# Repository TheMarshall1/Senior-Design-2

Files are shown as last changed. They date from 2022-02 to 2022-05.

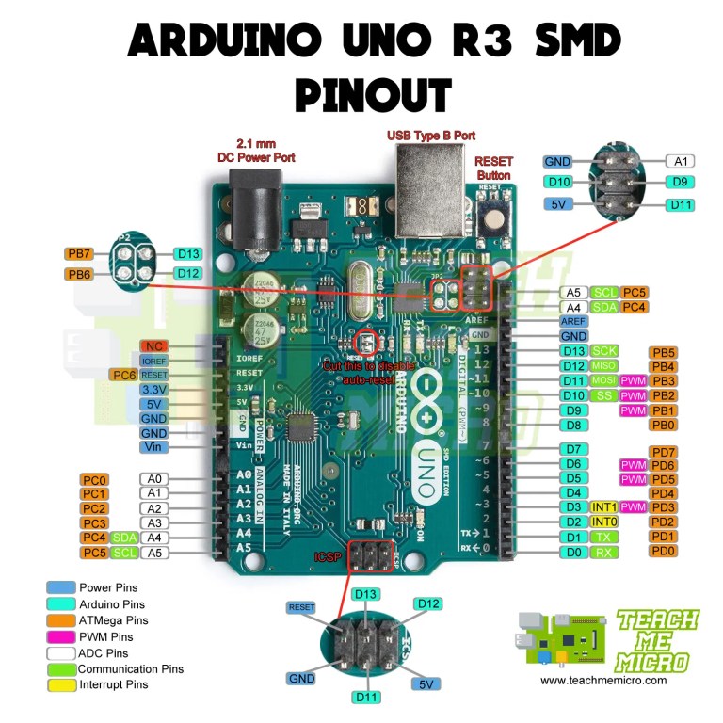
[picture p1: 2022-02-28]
DataSheet/PCB-Data/arduino pin layout.jpg

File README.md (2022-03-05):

# Team GoGetters
### Purpose, Objective, Introduction:
The problem our team is trying to tackle is wandering in dementia patients. Alzheimer’s
disease or other dementia causes people to lose their ability to recognize familiar places and
faces. It’s common for grandparents living with dementia to wander or become lost or confused
about their location, and it can happen at any stage of the disease. Although common,
wandering can be dangerous and the stress of this risk weighs heavily on caregivers and family.
### Solution:
The project is designed to give the patient around the clock care. It is a sensor system
consisting of two boards. First, a weight sensor that is located under the patient mattress and
motion sensor near the bed work together to collect and analyze data with an Arduino
microcontroller. Second, an IR sensor that is able to tell if the patient is leaving the room. The
code reads the input from the sensors on each of the two Arduinos (Client Arduino and Server
Arduino) and notifies the server Arduino directly or over wifi from the client Arduino. Then the
server Arduino changes the webpage to notify the user.
Scope:
Continuing from our first semester prototype, our team will focus on achieving the goals
defined in the Tasks and Deliverables section. This document will keep track of the task needed
to be done .
### Teams Link
https://teams.microsoft.com/l/channel/19%3aRfTW1WtWi_rlrrXjveJYQXDsdVA2zwDeV-sNyXwoO8I1%40thread.tacv2/General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

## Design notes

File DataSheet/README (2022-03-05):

This folder contains all the components' schematics and datasheet

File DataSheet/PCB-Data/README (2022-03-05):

This folder contain the general info for the battery/logic board designed by Khanh Le via Altium

Main functionality:

Battery Reverse Voltage Protection.
Low Battery Detection LED.
Alarm Signal Processing

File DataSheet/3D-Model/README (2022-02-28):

This Folder contains the 3D printed container's files and pictuces 
The components are sampled to create the container
The container is designed by Khanh Le using FreeCAD

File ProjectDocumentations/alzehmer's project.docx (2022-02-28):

8) Data configurationally management plan

Alzheimer's disease affects one out of every nine adults 65 and older as well as up. “On such an annual basis, family members expend upwards of $1 million dollars providing with someone with Alzheimer's disease. Sometimes households will have to forego vacations as a result of this. Individuals, but at the other hand, might even go desperate for food.”

These information, directly taken out from Alzheimer's Association, should provide anyone an idea of something like the difficulties that an individual experiences because they or a significant one seems to have Alzheimer's disease. As little more than a manufacturer, I considered this now and wanted to create a reusable gadget, a technology that really can assist both patients and family members.

That system will be able of doing at least those two activities:

- Encouraging the customer to complete regular chores (such as medications, exercise, etc)
- Monitoring your participant's location in the household; notify the caregivers inside the case of emergencies; and indicate the moment (it's a timepiece, and besides!)
- It really should be transportable as well as simple to be using, for even an elderly woman. It really should be inexpensive.

9) Software development model

It may have been used to identify if indeed the patients has collapsed as well as to determine where another patients would be in the house using precision temperature monitoring.

- Nokia 55-inch
- Touchscreen,
- Sensors
- Arduino
- HC-05 Transmitter And receiver

Methodology

This DPS310 atmospheric sensing element on Infineon's Encourage Interaction Nano development board provides data across wirelessly to the development board. Infineon's Mobile application, but also the SES2G assessment programme, can display pressure, temperature, and temperature measurements. Users can even use the Arduino library to create their customized Mobile application based on their needs. However, I'd like Alzheimer's Assistant to function with the use of a Samsung head in the middle. That should be a self-contained comfortable to wear with the ability to combine to a computer in order to examine data from the sensors. So, because of its small footprint size plus Wireless internet functionality, I chose to utilise another Arduino MKR1000 controller and interface it to the Encourage Interaction Micro or use some technique.

The Microcontroller MKR1000's configuration is as follows. Because I had an HC-05 bluetooth module on hand, I had to utilise it to link the Arduino MKR1000 to the Sensor Hub Nano. However, we must first wire the HC-05 towards the Arduino's hardware Tx & Rx pins, keeping into mind the transistor logic.

Because my wireless system operates as higher voltage, the same with the Construct different, no multilevel inverter translator was required. However, if my embedded system operates at 5 volts, you may need to utilise a pedestrian level. After we've matched the voltage levels, we'll really do have to couple the Administered intravenously now with Directly Interact Micro to begin transmission of data, and we'll need to figure out a simple way to have them pair periodically whenever the Directly Interact Micro comes within range of the network of something like the Makes the work.

To accomplish this, I decided to set up my HC-05 as a bluetooth'master' controller, pairing it mostly with one Network interface: the Directly Interact Nano's. So, even after you've configured it that way, when we power upon that HC-05, it looks for something like a gadget with such a specified Network interface (the Directly Interact Nano's) and immediately couples with this now, permitting the user to communicate with other devices.

Consequently HC-05's AT configuration parameters are used to accomplish this.

Code

// Original sketch from Martyn Currey's blog here:

// http://www.martyncurrey.com/arduino-with-hc-05-bluetooth-module-at-mode/

//

// Sketch modified by me to work with Arduino MKR1000!

//

// Basic Bluetooth sketch

// Connect the HC-05 module and communicate using the serial monitor

//

// The HC-05 defaults to commincation mode when first powered on.

// Needs to be placed in to AT mode

// After a factory reset the default baud rate for communication mode is 38400

char c = ' ';

void setup() {

// start the serial communication with the host computer

Serial.begin(9600);

Serial.println("Arduino with HC-05 is ready");

// start communication with the HC-05 using 38400

Serial1.begin(38400);

Serial.println("Serial1 started at 38400");

}

void loop() {

// Keep reading from HC-05 and send to Arduino Serial Monitor

if (Serial1.available())

{

c = Serial1.read();

Serial.write(c);

}

// Keep reading from Arduino Serial Monitor and send to HC-05

if (Serial.available())

{

c = Serial.read();

// mirror the commands back to the serial monitor

// makes it easy to follow the commands

Serial.write(c);

Serial1.write(c);

}

}

Final preparations

I could have used a Battery system with the Construct different but it does have a port for it. But then as We do not really have this at this present, I won't go into detail about it; nevertheless, if you ever need more details, your could visit the webpage for something like the Arduino Construct different.

We had 2 alternatives regarding recharging: visitors can use the MKR1000 USB connector directly, or you can use wireless charging if you have it. I'm going to use removable batteries for it. Because I already own an inductive charging transponders, that was not an option.

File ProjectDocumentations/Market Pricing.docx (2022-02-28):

Market pricing

The market pricing of the whole device will be roughly $170. It based on the area of the house we want to cover. In this price, the device will cover 3 bedrooms, a lounge, kitchen and 2 bathrooms. So, if the requirement of the space is more then, the price of the device will rise to $230-250 considering the need of more motion sensors and alarms.

Cost to make:

The motion sensors will cost about $50. More than 20 motion sensors will be required. When it comes to the Arduino microcontroller, the cost varies and if they will be bought in more quantity then their price will be less as compared to buying them individually. The price of a single unit is $15-20. Alarms and LEDs on the other hand will cost roughly $100 to buy and then integrating with the system.

Competitor

When it comes to the competition of this device, there are some devices of similar nature available in the market such as Tru Sense and Rest Assured, but these are not standalone devices. These are complete systems that need to be integrated within your house and they are based on monthly subscriptions. The cost models are not as effective as the proposed product “Grandma House”. This device is based on BOUF model (Buy Once Utilize Forever). Investment in this device is a one-time thing and it will last you almost forever considering the lifetime of Arduino microcontroller and the motion sensors.

Market Size

The market size of this product is not as vast as the baby monitoring devices because about 50 million people around the world have Alzheimer's disease or another type of dementia. The data set from the World Health Organization (WHO) revealed that about 60% of people living with dementia and/or Alzheimer’s are from a low or middle-income country throughout the globe. That is why the market size of devices of Grandma House nature are not as popular as the remote baby monitoring devices.

Sell Price/ Value

When it comes to the selling price or market value of this device. It can be considered as mediocre to high. Since there are no similar devices available in the market, it is safe to say that Grandma House: Alzheimer’s Monitoring Device is one of a kind that needs to be valued at a normal rate in the beginning so that people from all socioeconomic backgrounds can get to afford it. The data from WHO revealed that the global 60% population with Alzheimer’s disease is from middle-income earning countries. With the passage of time, the market value and the selling price will be increased as per the normal business models.

Percent Profit

For now, there is very less percent of profit from selling this device because we want the market and the target audience to be familiarized with it. Once the device is completely introduced to the intended audience, the profits can be estimated at 5% per device that means the profit will be $10 per unit.

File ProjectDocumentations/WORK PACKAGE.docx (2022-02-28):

WORK PACKAGE

- For this semester, there are quite a few things that still need to be done. The major items on my list, I will outline below.

Strain Ga. (Phuong) | IR (Abdul) | Build (Khanh) | Test (Mutlaq) | WiFi (Marshall) | Integration
Calibrate | Prox. Sensor | 3D model | Give parameters of the project | Setup | Make the story work
Weight-Value (The breakdown weight it can handle) | Daylight/Night | Hooking everything up | Environmental Factors (different lighting, door frames, bed weights) | Protocol | Keypad/finger sensor
Test | LED/Fluorescent | Battery(Arduino, Sensors) | | peer to peer | TA at Nov/20
Zeroize | code into arduino | Enclosure | | dhcp
Code into Arduino
arduino uno with HTTPS | arduino uno with HTTP

My task will be focus on how to test the project by give parameters of the project and environmental factors (different lighting, door frames, bed weights).

We worked this week with our project and we build it and connected the wight sensors and Arduino after we upload the code on it. Then we calibrated but it didn’t work. We plane to fix the code again and do the test again.

For next semester, there some of things need to be done. The major items on my list, I will outline below.

- Evaluate the project and correct any mistake from the previous semester.
- Rework on the design of the project and check availability of any sensors.
- Work on the finger touch and make alarm via SMS that the patient moved from the bed.
- Adjust the sensors on bed frame or on the door frame.

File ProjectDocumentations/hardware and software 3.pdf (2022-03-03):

Architecture Requirements
Task, Deliverable, or Feature Requirement | Description of Requirement
Powering the system | To power the system, we need to get 5volts, the supply will come from the mains ac source, then using a switching mode power supply we will convert the power from AC to 5v DC, the current should be minimum 2A to make sure that the system will operate in a good voltage level without flickering or dimming since we are using GSM modem and it requires 1A.
Connecting the Arduino to weighing sensor (using data pin and clock pin) | The load cell outputs cannot be connected directly to the Arduino, although Arduino board can detect small changes in voltage (4.9 mV) but this resolution still not enough for reading from the load cells, a dedicated amplifier board is being used to amplify the load cell voltage. To connect the sensor a synchronous serial protocol is used via two pins one for the data and the other for the clock signal.
Connect the load cells to the Hx711 board | The board Hx711 can be used with two or four cells, in this system we will use four load cells to put them under the bed legs, the four load cells will read the weight of the bed added to the human weight, hence controller can detect when the human leaves his bed.
GSM modem (Serial) | GSM modem communicates with the Arduino using two serial pins (Tx) which is the transmitter and this pin should be connected to a digital pin on the Arduino to work as receiver, the other pin is the (Rx) pin which is the receiver pin, this pin should be connected to digital pin on the Arduino board to act as serial transmitter

Software Requirements

IR sensors (Analog) | A set of two IR sensors will be used in this system, the output of the IR sensor is an analog voltage that is reverse proportional to the distance, a threshold will be assigned and the sequence of the sensors triggering will specify the movement direction, this method will be used to detect whether the patient is entering or leaving the room.
Task, Deliverable, or Feature Requirement | Description of Requirement
Arduino IDE | The Arduino integrated development environment is the platform needed for writing the Arduino code, the Ide can be installed on windows or mac laptops, even there is a web-based version of this software. All manufacturers of the sensor and actuators build a library for their product to make easier to use for Arduino developers, for this purpose the Arduino IDE can be loaded with tons of sensor libraries.
HX711 library | This board library helps to read the analog to digital conversion result, this board has 24bit ADC while the Arduino has 10bit ADC, this means high precision reading for small voltages coming from the load cells. The library has read command which will do the required communication with the board and get the result of the weight stored on the Arduino ram.
GSM library | GMS modem and most modem types are communicating with controllers using Serial protocols which is called UART (universal synchronous a synchronous receiver transmitter. This protocol will be used to send ASCII commands called (AT: attention) commands. For each GMS modem there are a pdf file that exactly specify the required AT command for doing certain task like sending SMS or make a call or even read the operator’s name and time.

IR sensor analog read | Ir sensor gives analog output , there are a library on the Arduino to read the analog voltage from any analog pins from A0 to A5.

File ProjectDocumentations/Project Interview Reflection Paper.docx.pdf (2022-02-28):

# Product Interview Reflection paper

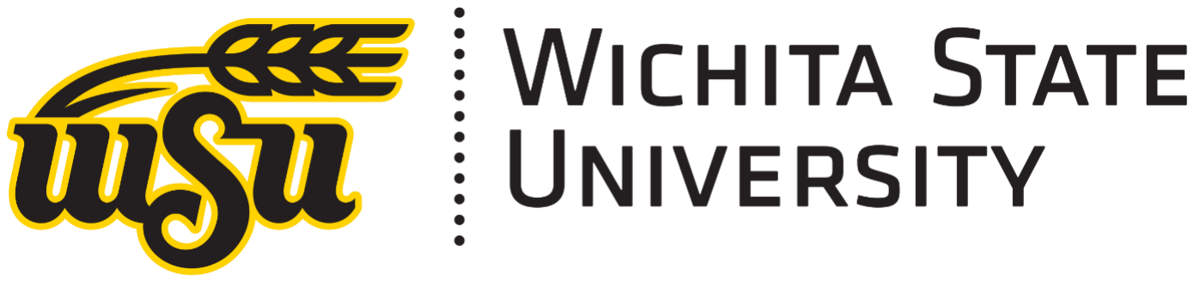
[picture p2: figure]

Class: EE 585

Team Name: Go Getter

Team Members: Marshall Aurell, Phuong Nguyen, Mutlaq Alotaibi, Khanh Le, Abdull Alhoulan

Project Name: Grandma’s House

Date: 11/7/2021

Introduction

With wandering being a major issue when it comes to helping people who

are dealing with dementia, there was a need for a solution. The Grandma’s House

system is a smart solution for the problem stated. Our system provides the

caretakers with a solution that will be able to identify when the risk of a person

with dementia is wandering around unattended and could seriously injure

themselves. During the week of November 7th we had the opportunity to ask

several people with diverse backgrounds a series of questions aimed at helping

our system cover a multitude of problems it could face. The information was

gathered and was analyzed by all team members. The team interviewed two

nurses at dementia & Alzheimer’s care centers, and a faculty member Md Rakib

Ur Rahman. The interviews covered these points, was there a product in place for

something like wandering, pricing, typical things we should know about the

patients to improve our project, and placement of the product to remain

concealed.

Body

Interview (1): Sandy from ComfortCare:

ComfortCare is an assisted living facility for dementia patients in Wichita,

KS. We informed her that our project is aiming to help caregivers of dementia

patients. We asked her how often the patients wander around and how far could

they wander? She said they are allowed to wander around the inside of the

building, but they must be accompanied by a caretaker outside the building. Then

we asked what kinds of sensors and systems that facility is using and how do they respond? Sandy said they have a bedtime alarm system in place that will sound an

alarm when it's time for them to go to bed.

Aslo, we asked how much did they spend on each sensor product and did

they have all the rooms installed with the product? She didn't have a price right

now but she also mentioned that healthcare products are expensive. We asked

Sandy would she spend $200 for a sensor system like ours? She replied yes, that

would be an awesome price range. Besides the strain gauges, Sandy said, the

facility is currently not using any types of motion detection or motion sensors to

detect patients are leaving their rooms. They would like our system to be able to

send a text message to someone that is on duty there and not to someone that

hasn’t checked in for the day. Also, the caretakers would like it if they would be

able to turn off the system when it is not needed.

Interview (2): Md Rakib Ur Rahman:

Rakib is an PhD electrical engineer student and a TA for the course. We set

up a meeting with him to ask about some technical issues the project may have.

We asked him about various problems regarding the project’s functionality. We

had a question for him about our battery powered board. After we did my

calculation for the power consumption, we thought that as the battery is drained,

the internal regulator of the Arduino won’t be able to keep up. Rakib advised us

that we should do some testing and get data voltage drop and the internal load of

the assembly first before deciding on if we want an extra regulator.

When asked about the environmental factors (different lighting, door

frames, bed weights) that can affect the system. He gives a suggestion about an

extra motion sensor and how we can arrange it around the bed frame. This extra motion sensor can eliminate some of the factors that we are worried about. One

other problem we asked him is about the project’s communication method. When

the system gets interrupted, we think it will not reboot correctly. Although he

cannot answer the question right away, he will connect us with someone who is

knowledgeable about the subject.

We asked him if we can use finger touch and he responded that we will work

on that if we are done with the test of our project.

Interview (3): Michelle from Brookdale:

Brookdale Senior Living owns and operates senior living communities and

retirement communities across the United States. We were able to talk with

Michelle for the interview. Michelle is currently working as a nurse for a Brookdale

facility in Wichita. We informed her about our project which aims to help

caregivers of dementia patients. She said that the sensor system would cause a

restraint to the staff and that they cannot use such a sensor system because it

would go against their company policy. Instead, they use call lights, fall mats, and

frequent checks (10 – 20 minutes). When we asked if the facility had any system

in place to prevent wandering. She mentioned that their building has an exit alert

system which would go off when someone without a passcode wanders outside.

Conclusion

Using these interviews, we can break down the main points that can be

learned regarding target market, product features, functionalities and pricing:

At first, the main vision for the project’s market was for resident homes. It

was designed to help family members of dementia patients to look after them better. But after the interviews with the care facilities, we learned that the scope

of the project should be modified toward these care centers. We have decided

that extra features should be added based on the feedback from these care

centers. The first changes would be instead of the 24/7 sensor system, we will

need to add an on/off button (could be a switch, keypad or fingerprint scanner).

Second, the sensor system should be able to integrate with their existing

employee management system. This integration would require a lot of time and

coding so we have decided to include this to next semester's workload.

As for the current functionalities of the product. We have decided to add an

extra motion sensor near the bed of the patient. This sensor will share the same

Arduino board as the strain gauge. This extra component will help create a more

accurate alert.

The main focus of this product is reliability and the affordability of each

product that we can provide for the customers. From the interview we conclude

that the customers want the products installed in their facility if the cost is

affordable for not only the facility but also the patients they are caring for. We

know it would cost a lot less to install the system to help prevent wandering and

monitoring the situation before the accident happens than in the situation that

the patients wandering around get lost or get hurt.

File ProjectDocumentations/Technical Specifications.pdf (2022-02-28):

# Technical Product Specification Paper

Class: EE 585

Team Name: Go-Getter

Instructor: Caskel Stallard

Date: 10/24/21

Product description: This device will consist of two parts. First, a sensor system that is located under the patient bed and throughout the house to collect and analyze data with an Arduino microcontroller. Each sensor will have an RF24 module and Arduino Nano to transfer data wirelessly. Second, an alarm that is designed to go off and send an SMS notification to the caregiver when the system indicates that grandma is doing something unusual.

General requirements:

- Indoor environment:
- Temperature Range: 60-80 F
- Humidity: 30-50%
- Internet service: wireless connection for LAN configuration.
- Telecommunication devices with service connection

Alternate Considerations:

Changes | Reason | Pros | Cons
Use IR sensor instead of PIR sensor | PIR has a wide detection range and will interfere with other PIR sensors when put in close proximity | _IR allow directional detection
Use SMS as an alarm instead of emails | People tend to check their messages more than emails | _SMS is more effective as a notification tool | _After using more than 90MB, we have to pay to use the service _Estimate around $5-10 per month
Use RF24 transceiver module | As the project scopes grow from a room to a house, wiring all the modules together is not practical. | _Allow wireless data transfer in | _Extra cost _Each module need its own power supply

Regulations:

- Battery:
- Follow the American National Standard for Portable Lithium Primary Cells and Batteries Safety Standard (ANSI C18.1M Part 1-2001).
- Wireless:
- The wifi has to comply with IEEE 802.11 n/g/b standard.

- The RF transceiver module must comply with FCC Equipment Authorization for RF Device (Products operating at 9 kHz to 3000 GHz have the potential to cause interference with radio services).
- Sensor: (Strain gauge, IR motion sensor)
- All boards must comply with RoHS Directive (lead-free solder finish and meet the
| restricted concentration levels for dangerous chemicals such as mercury,
| cadmium, hexavalent chromium, etc.)

Market pricing:
The market pricing of the whole device will be roughly $170. It is based on the area of the house we want to cover. At this price, the device will cover 3 bedrooms, a lounge, a kitchen, and 2 bathrooms. So, if the requirement of the space is more then, the price of the device will rise to $230-250 considering the need for more motion sensors and alarms.
Cost to make:
The motion sensors will cost about $5. More than 20 motion sensors will be required. When it comes to the Arduino microcontroller, the cost varies and if they will be bought in more quantity then their price will be less as compared to buying them individually. The price of a single unit is $15-20. Alarms and LEDs on the other hand will cost roughly $100 to buy and then integrate with the system.
Competitor:
When it comes to the competition of this device, there are some devices of similar nature available in the market such as True Sense and Rest Assured, but these are not standalone devices. These are complete systems that need to be integrated within your house and they are based on monthly subscriptions. The cost models are not as effective as the proposed product “Grandma House”. This device is based on the BOUF model (Buy Once Utilize Forever). Investment in this device is a one-time thing and it will last you almost forever considering the lifetime of the Arduino microcontroller and the motion sensors.
Market Size:
The market size of this product is not as vast as the baby monitoring devices because about 50 million people around the world have Alzheimer's disease or another type of dementia. The data set from the World Health Organization (WHO) revealed that about 60% of people living with dementia and/or Alzheimer’s are from a low or middle-income country throughout the globe. That is why the market size of devices of Grandma House nature is not as popular as the remote baby monitoring devices.
Sell Price/ Value:
When it comes to the selling price or market value of this device. It can be considered mediocre to high. Since there are no similar devices available in the market, it is safe to say that Grandma House: Alzheimer’s Monitoring Device is one of a kind that needs to be valued at a normal rate in the beginning so that people from all socioeconomic backgrounds can afford it. The data from WHO revealed that the global 60% population with Alzheimer’s disease is from middle-income earning countries. With the passage of time, the market value and the selling price will be increased as per the normal business models.
Percent Profit

For now, there is very little profit from selling this device because we want the market and the target audience to be familiarized with it. Once the device is completely introduced to the intended audience, the profits can be estimated at 5% per device that means the profit will be $10 per unit.
Software details :
1. Each Arduino will be equipped with an RF24 that will send a signal back to the main Arduino wirelessly, then the main Arduino will interpret the information and will send an SMS message to the caretaker's phone.
2. A recording device will have the following sensors attached:
a. IR Sensor / Weight Sensor
b. Fingerprint Scanner (Deactivate the system if a caretaker is going into that location. And reactivate the system when caretaker leaves)
3. Depending on the location of the sensors it will notify the caretaker of the whereabouts of the patient by sending an SMS message to their mobile devices

Design Specifications (Hardware):

- The product will come with 3 different modules minimum, all batteries powered. All
| modules will have an enclosed, rectangular case.
- The RF24 transceiver network (communication method between Arduino units/modules) must be able to operate with 20+ nodes within a 1500-2500 sq ft residence.
- Case enclosure must meet IP64 of International Protection ratings, meaning it offers total
| protection against dust and protection against water splashes from all directions.

Design Specifications

Arduino Processor Board

| Dimensions | 13.7 x 8.4 x 1.85 in.

| Weight | 2.15 lbs.
| Operating Voltage | 3.3 V to 12 V
| Compatible | PC and Mac
| Software | Arduino IDE

Battery Cell

| Voltage | 12 V

LED

| Color | Red, Yellow, Blue, Green

RF24 Receiver Module

| Operating Voltage | 3.3 V
| Range | 50 to 200 feet
| Frequency Range | 9 kHz to 2.4 GHz

Weight sensors

| Load Weight (4 pieces) | 50 Kg. X 4

HX711 AD Module

| Operating Voltage | 2.6 V – 5.5 V

| Item Weight | 2.8 ounces
| Dimension | 5.71 x 4.17 x 0.67 in.

Infrared Proximity Sensor

| Dimensions | 29.5 x 13 x 21.6 mm
| Range | 20 to 150 cm
| Operating Voltage | 4.5 V to 5.5 V

WIFI

| Comply With | IEEE 802.11 n/g/b standard

Communication

| Type | SMS

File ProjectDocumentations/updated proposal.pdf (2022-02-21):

## Team GoGetter

### Project Proposal

Product Title:

“Grandma House”

Primary Project Proposal:

Alzheimer’s disease or other dementia causes people to lose their ability to recognize familiar places and

faces. It’s common for grandparents living with dementia to wander or become lost or confused about

their location, and it can happen at any stage of the disease. Although common, wandering can be

dangerous and the stress of this risk weighs heavily on caregivers and family. The project is designed to

detect your grandma or loved one's rising from bed by monitoring his/her body weight and motion. It

also detects the location of grandma within the house. An alarm will go off when the system detects

anything “abnormal” about the grandma's location.

Product Description:

This device will consist of two parts. First, a sensor system that is located under the patient bed and

throughout the house to collect and analyze data with an Arduino microcontroller. Second, an alarm/LED

that is designed to go off when the system indicates that grandma is doing something “abnormal”.

Requirements:

1. Using weight sensors such as strain gauge to determine when the patient leaves their bed.
2. Using different motion sensors and infrared sensors to determine when the patient (leaves their

room/enters another room).

4. Transmission of all collected data to a microprocessor (Arduino) and send it to a web server.
5. When the patient leaves their bedroom during an unwanted time and the movement system indicates

that the patient has left the room/house, the system will set an alarm to notify their caregivers.

6. The system will be hidden out of sight and without any wearable accessories.
7. Integrate the alarm and the sensor system with wireless communication (RF transceiver)

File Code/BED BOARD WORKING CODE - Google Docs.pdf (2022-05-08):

//Include Libraries
#include <SPI.h>

#include <nRF24L01.h>

#include <RF24.h>

#include "HX711.h"

#define pir 4

const int LOADCELL_DOUT_PIN = 2; const int LOADCELL_SCK_PIN = 3; float a;
float b=60;

HX711 scale;
//create an RF24 object
RF24 radio(9, 8); // CE, CSN

//address through which two modules communicate. const byte address[6] = "00001";

void setup()
{
pinMode(pir,INPUT);
radio.begin();

//set the address
radio.openWritingPipe(address);

//Set module as transmitter
radio.stopListening();

Serial.begin(9600);
scale.begin(LOADCELL_DOUT_PIN, LOADCELL_SCK_PIN);

scale.set_scale(2280.f);
scale.tare();
}
void loop()
{
if (digitalRead(pir)==1){
Serial.println("Motion detected"); delay(1000);
}

Serial.print("one reading:\t"); Serial.print(scale.get_units(), 1); Serial.print("\t| average:\t"); Serial.println(scale.get_units(10), 1);
a = scale.get_units(10);

if (a>b && digitalRead(pir) == 1){ Serial.print("Some one is on bed and moving\n"); const char text[] = "ON bed moving"; //13 char radio.write(&text, sizeof(text));
delay(1000);
}
else if (a<b && digitalRead(pir) == 1){
Serial.print("Some one is NOT on bed and moving \n"); const char text[] = "NOT bed moving"; //14 char radio.write(&text, sizeof(text));
delay(1000);
}
else if (a>b && digitalRead(pir) !=1){ Serial.print("Some one is on bed and not moving \n"); const char text[] = "ON bed not moving"; //17 char radio.write(&text, sizeof(text));
delay(1000);
}
else if(a<b && digitalRead(pir) !=1){
Serial.print("Some one is NOT on bed and not moving \n"); const char text[] = "NOT bed not moving"; // 18 radio.write(&text, sizeof(text));
delay(1000);
}
scale.power_down(); | // put the ADC in sleep mode
delay(5000);
scale.power_up();

}

DOOR BOARD

//Include Libraries
#include <SPI.h>

#include <nRF24L01.h>

#include <RF24.h>

//create an RF24 object
RF24 radio(9, 8); // CE, CSN

//address through which two modules communicate. const byte address[6] = "00001";

#define sensor1 5 //black In IR

#define sensor2 6 //white Out IR #define alarm1 2

#define alarm2 3

#define sms 4

#define LED 7

char dir;

void setup()
{
while (!Serial);
Serial.begin(9600);
radio.begin();

//set the address
radio.openReadingPipe(0, address);

//Set module as receiver
radio.startListening();

pinMode(alarm1, OUTPUT);
pinMode(alarm2, OUTPUT);
pinMode(LED, OUTPUT);
pinMode(sms, OUTPUT);
pinMode(sensor1,INPUT_PULLUP); pinMode(sensor2,INPUT_PULLUP);

dir='x';

}

void loop(){

digitalWrite(alarm1,HIGH); digitalWrite(alarm2,HIGH); digitalWrite(sms, HIGH);
digitalWrite(LED, LOW);
const char a[32]={"ON bed moving"}; //14 const char b[32]={"NOT bed moving"}; //15 const char c[32]={"ON bed not moving"}; //18 const char d[32]={"NOT bed not moving"}; //19 char text[32]={0};
int w;
//Read the ata if available in buffer

if (radio.available())
{
radio.read(text, sizeof(text)); //String mytext =String(text); Serial.println(text);
//w= mytext.length();
}

if (digitalRead(sensor1)==0){//sensor 1 detects object

if (dir=='x'){//if the last movement was unkown dir='o';//movement is out going
//give 2 seconds before ignoring the direction
Serial.println("direction is Out");
delay(1000);

if (dir =='o'&& (sizeof(text)== sizeof(b) || sizeof(text)== sizeof(c)) ){ //still not bed not moving || not on bed while moving (18 || 14)
digitalWrite(alarm1, LOW);
digitalWrite(alarm2, LOW);
digitalWrite(sms, LOW);
delay(1000);

}
else if (dir =='o' && (sizeof(text)== sizeof(a) || sizeof(text)== sizeof(d))){ //still on bed not moving && still on bed while moving (17 || 13)
digitalWrite(LED, HIGH);
delay(1000);

}
dir='x';
}
}

if (digitalRead(sensor2)==0){//sensor 2 detects object

if (dir=='x' && sizeof(text)==sizeof(a)){//if the last movement was unkown dir='i';//movement is out going
//give 2 seconds before ignoring the direction
Serial.println("direction is IN");
dir='x';
delay(1000);
}

}

}

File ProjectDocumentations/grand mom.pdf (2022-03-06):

Ac power supply

In this report I will explain the power supply details for powering the circuit, the input

will be taken from the AC power outlet which is 110V AC,

The first step is to convert the ac voltage to DC voltage using SMPS, the adapter will

be selected to give 12V DC, although we need 5volt to supply the circuit but we will

use 12v adapter to use a buck converter that will step down the dc 12 volt to 5v dc, the

use of another stage for getting 5volts is due to the need for constant 5volts as will as

over current protection board.

Figure below shows the power adapter that will give 12v dc to the circuit

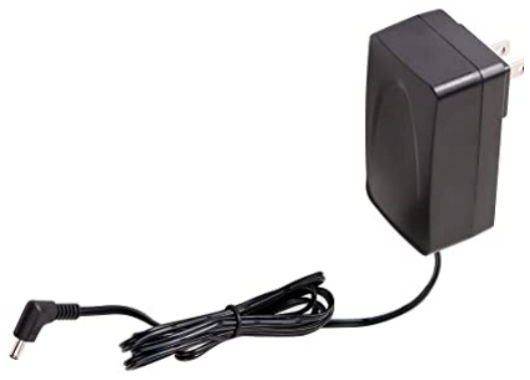
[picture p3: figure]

Features and specs of the adapter as taken from the reference 1

- AC input ranges from 100V to 240V, 50Hz/60Hz, 0.8A Max; DC output 12V 2A
- 12v 2a AC adapter with 4ft long cable enables you to conveniently make an

easy connection

Figure below shows the Buck converter which will step down the voltage from 12V DC to 5V DC and at the same time it does the overcurrent protection as well as the over

temperature protection

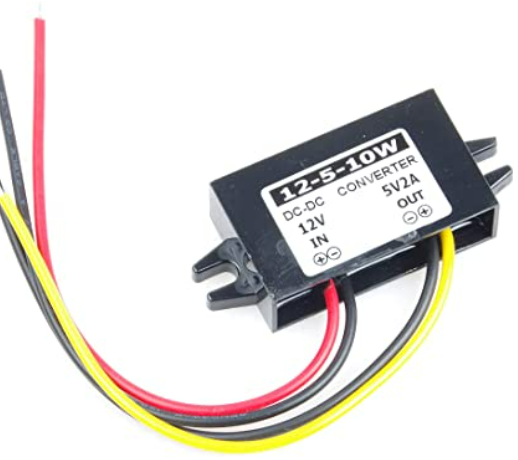
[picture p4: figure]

Features and specs as taken from reference 2

- Synchronous rectification, efficient, stable and reliable.
- Input voltage: 12V (higher than the output voltage of 3V) the maximum 20V

(DC 8- 22V)).

- With over-temperature protection
- overcurrent protection
- short circuit protection
- Output voltage: 5V
- Conversion efficiency: > 93%.
- Waterproof level: IP67.Shockproof

Finally figure below shows the connection diagram of the power supply circuit, it will

take the 110v from the power socket and convert it to 12v using the power adapter,

then the buck converter will stepdown the voltage to 5volts and make the required

protections, over heating and short circuit protection and also the over current, on the

output of the buck converter we added the switch button to turn on/off the supply

voltage

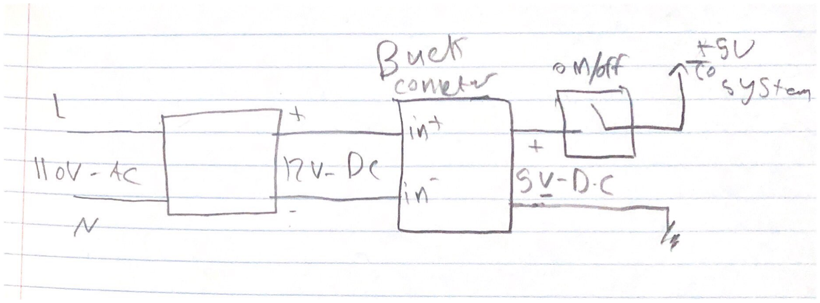
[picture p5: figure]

Reference

1. https://www.amazon.com/DTECH-Adapter-Supply-1-35mm-Charger/dp/

B082XWGGKJ/ref=sr_1_2_sspa?

crid=MFZ37N9MYEPA&keywords=smps+12v+2a&qid=1646465403&spr

efix=smps+12v+2%2Caps%2C225&sr=8-2-

spons&psc=1&spLa=ZW5jcnlwdGVkUXVhbGlmaWVyPUFGNUZLV1hBM

UNPSkcmZW5jcnlwdGVkSWQ9QTA2NzM2MjVCVDFJSk9GN0paM1kmZ

W5jcnlwdGVkQWRJZD1BMDUyMDQ3NlExT1FNQjVZOUc1VSZ3aWRnZX

ROYW1lPXNwX2F0ZiZhY3Rpb249Y2xpY2tSZWRpcmVjdCZkb05vdExvZ0

NsaWNrPXRydWU= (https://www.amazon.com/DTECH-Adapter-Supply-1-35mm-Charger/dp/B082XWGGKJ)

2. https://www.amazon.com/KNACRO-Synchronous-Over-Temperature-

Over-Current-Protection/dp/B08RMYX25Y/ref=sr_1_4?

crid=1WTHOJL2SN8S9&keywords=buck+converter+overcurrent+protect

ion&qid=1646465948&sprefix=buck+converter+overcurrent+protection%

2Caps%2C224&sr=8-4 (https://www.amazon.com/KNACRO-Synchronous-Over-Temperature-Over-Current-Protection/dp/B08RMYX25Y)

3.

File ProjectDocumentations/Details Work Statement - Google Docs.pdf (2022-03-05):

- Hardware requirements will be completed.
Deliverables | Assigned to | Due Date (Week/Date)
Possible Logic PCB to analyze the logic (Altium) ● Input: from all the function in the code ● Output: a signal connected port #(SMS function) to generate a SMS when high ● Design schematic, footprint, component library, PCB layout. | Khanh Le | 2/13 (Week 4)
Transceiver testing to transfer information between Arduino boards ● Ability to send an input to another arduino through the use of a transceiver channel ● Code the software to set up a communication pathway between both transceivers | Marshall | 2/27 (Week 6)
New 3D printed enclosure ● Update for new circuit+ power supply+wires from last semester | Khanh Le | 3/20 (Week 9)
Alarm Logic for the whole system ● Digital design*(help with memory storage) ○ Logic diagram ○ Logic map | Khanh Le | 2/20 (Week 5)
SMS module ● Research (due 2/20) ● Use SIM card to send SMS | Mutlaq | 2/27 (Week 6)
On/Off Switch for power supply ● A switch ● Circuit protection (diode) | Phong | 2/27 (Week 6
AC power supply compatible ● Circuit protection | Abdul | 2/27 (Week 6)

Software requirements will be completed.

Deliverables | Assigned to | Due Date (Week/Date)
Read and auto calibrate/zeroize strain gauge function (Github) ● Input: Take digital signal from strain gauge. ● Calibrate: translate the signal to a unit of measurement (kg) ● Zeroize: Zero out the weight detected in the first 15 second ● Output: A signal to the logic board | Phong | 2/27(Week 6)
Detect movement, IR break function (Github) ● Input: Take analog signal from sensors ● Output: A signal to the logic board ● Take into account light sources, distances,... | Abdul | 2/27 (Week 6)
Wifi Connection Function(Github) ● Option 1: Use two Arduino Uno to make a host and client network. Let the host control the web server and host a webpage. Allows clients to access webpage and keep track of the alarm status ● Option 2: Same thing, but using transceivers to tie the two arduinos together and using SMS to notify the caretakers | Marshall | 2/27 (Week 6)
Wifi Web Page UI (Github) ● User friendly/ working interface ● Shows alarm status ● Shows current data of sensors? | Marshall | 3/13 (Week 8)
Sending SMS Function (Github) ● Input: Take data from sensors ● Output: Alarm caretakers if sensor data is in the parameters | Mutlaq | 3/6 (Week 7)
Add time to Arduino and webpage (Github) ● Connect the Arduino to wifi and using the NTP to get the time and date ● Or RTC clock | Abdul | 3/6 (Week 7)

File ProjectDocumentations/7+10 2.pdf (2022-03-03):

### 7 ACQUISITION SCHEDULE

To achieve the project goals, we must divide our work into small tasks and we will

allocate a certain time period for each task, every task is a milestone in the project and

has to be done at the dedicated time in order to open the working process of the next

task, the main controller will monitor all the inputs and outputs is the Arduino board, it

will sense the human weight using four load cell that will be installed under the user

bed for example installing a load cell on each leg of the bed, the load cells will

measure the bed weight including the weight of user, and will detect the user existence

depending on the weight.

Week | Acquisition Schedule: 1 st Semester | Cost
Week 6 | • Studying the block diagram • Search for desired components • Compare prices and delivery dates | --
Week 7 | • Ordering main controller :15$ • Power supply 5v:12$ • Wires: 10$ • Usb cable 3$ | 40$
Week 8 | Purchase the weight sensor parts • 4 pcs 50kg Load Cells • HX711 | 12$
Week 9 | • Ordering IR sensors (detecting incoming or outgoing persons), this sensor should cover 1.5 meter with break beam sensing | 32$
Week 10 | Ordering WIFI modem • ESP8266 • Programming board (uploading code) | 20$
Week 11 | Ordering the prototyping components • Box • Base • connectors | 50$

### 10 FIRST SEMESTER SCHEDULE

The following table describes MLG’s first semester schedule:

Week 12 | Finalize the prototype | --
Week 13 | • Make desired modifications to both system and software | --
- TOTAL | | 154$
Week | Deliverable
Week 6 | • Design the system block diagram • Check compatibility between components
Week 7 | • Decide the main controller board • Decide the IDE for developing the code
Week 8 | • Ordering the components • Research about the available IOT clouds supported by the main controller board
Week 9 | • Assembling the weight sensor to the main controller • Develop test code to read and display weight
Week 10 | • Assembling IR sensors to the main board • Develop testing code for sensors
Week 11 | • Connect WIFI modem to main board • Program WIFI modem to connect to local Wi-Fi network • Develop code to send and receive data to WIFI modem
Week 12 | • Configure the selected IOT server to connect to our device • Program Wi-Fi modem with the desired IOT credentials • Send data from controller to cloud
Week 13 | • Run overall test • Make desired modifications to both system and software
Week 14 | • Finalize the final prototype • Make final real tests and modifications

Week 15

- Document the steps of work • Draw the final schematics and connections • Prepare and plan for next steps.

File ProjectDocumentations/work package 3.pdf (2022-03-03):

## Work package

In general, we are going to discuss how this system is going to be built, the tasks

needed to be performed as well as the required resources that must be existed to build

the system, for this purpose we need first to introduce the general idea of the system

that must be achieved then we will discuss the methods needed perform it

The main controller that will monitor all the inputs and outputs is the Arduino board, it

will sense the human weight using four load cell that will be installed under the user

bed for example installing a load cell on each leg of the bed, the load cells will

measure the bed weight including the weight of user, and will detect the user existence

depending on the weight.

To connect the load cells to the Arduino a special amplifier is required because the

output voltage of the load cells is very low.

Also, there are two IR obstacle sensors installed at the room entrance, we will use two

sensors to detect the person movement direction, if sensor1 triggered first then sensor

two this means the person is entering the room and if sensor two then sensor one, this means that the person is leaving the room.

Finally, the Arduino will send SMS to the responsible person telling him that the patient

left the room, this will be done by adding a GSM modem to the controller

Work needed to be performed

This system includes the following main field of knowledge

- Hardware assembling: this part should be easy and the connection diagram

between the components are available from the manufacturers

- Arduino programming: Arduino needed to be programmed using the Arduino

IDE program running on windows, programming requires good knowledge in C

programming.

- GSM modem: the GSM modem programming requires good knowledge and

skills in communication as well as the AT command for communicating with the modem, but fortunately there are a lot of Arduino libraries that deals with GSM

modems to send and receive messages.

Needed resources:

- Laptop for programming the Arduino
- Arduino IDE for writing the code
- SIM card to be inserted in the modem to send SMS
- Voltmeter to measure the system voltage and to test the IR sensor

Steps to finish the work

steps | Deliverable
Step1 | • Design the system block diagram • Check compatibility between components
Step2 | • Decide the main controller board • Decide the IDE for developing the code
Step3 | • Ordering the components • Research about the available GSM modems
Step4 | • Assembling the weight sensor to the main controller • Develop test code to read and display weight
Step5 | • Assembling IR sensors to the main board • Develop testing code for sensors
Step6 | • Connect GSM modem to main board
Step7 | • Configure the selected GSM to send SMS • Send data from controller to mobile phone
Step8 | • Run overall test • Make desired modifications to both system and software
Step9 | • Finalize the final prototype • Make final real tests and modifications
Step10 | • Document the steps of work • Draw the final schematics and connections • Prepare and plan for next steps.

Required products to finish the work

To achieve the project goals, we must divide our work into small tasks and we will

allocate a certain time period for each task, every task is a milestone in the project and

has to be done at the dedicated time in order to open the working process of the next

task, the main controller will monitor all the inputs and outputs is the Arduino board, it

will sense the human weight using four load cell that will be installed under the user

bed for example installing a load cell on each leg of the bed, the load cells will

measure the bed weight including the weight of user, and will detect the user existence

depending on the weight.

part | Acquisition Schedule: 1 st Semester | Required time (hours) | Cost
Arduino | • Ordering main controller :15$ • Power supply 5v:12$ • Wires: 10$ • Usb cable 3$ | 30 | 40$
Weight sensor | Purchase the weight sensor parts • 4 pcs 50kg Load Cells • HX711 | 10 | 12$
sensor | • Ordering IR sensors (detecting incoming or outgoing persons), this sensor should cover 1.5 meter with break beam sensing | 10 | 32$
GSM | Ordering GSM modem | 20 | 20$
casing | Ordering the prototyping components • Box • Base • connectors | 30 | 50$
- TOTAL | | | 154$

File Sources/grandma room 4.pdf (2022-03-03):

## Grandma room Block diagram

To achieve the project goals, we proposed the general block diagram shown in figure

1, the main controller that will monitor all the inputs and outputs is the Arduino board, it

will sense the human weight using four load cell that will be installed under the user

bed for example installing a load cell on each leg of the bed, the load cells will

measure the bed weight including the weight of user, and will detect the user existence

depending on the weight.

To connect the load cells to the Arduino a special amplifier is required because the

output voltage of the load cells is very low.

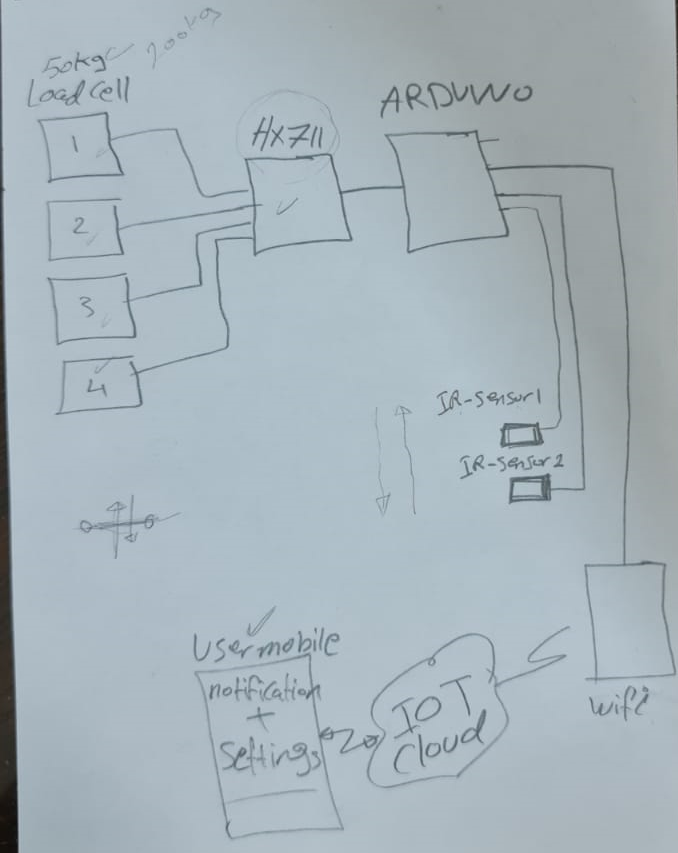
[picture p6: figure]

Figure 1 system block diagram

1

Also, there are two IR obstacle sensors installed at the room entrance, we will use two

sensors to detect the person movement direction, if sensor1 triggered first then sensor

two this means the person is entering the room and if sensor two then sensor one, this

means that the person is leaving the room.

Finally, the Arduino will upload the data and the notification to an IOT cloud using a Wi-

Fi connected to the Arduino, then the supervisor can open a dedicated mobile

application to connect his mobile to the cloud to monitor all sensors and get all

notifications, by using the IOT technology the mobile application can receive the data

from anywhere as long as the mobile has internet connection.

2

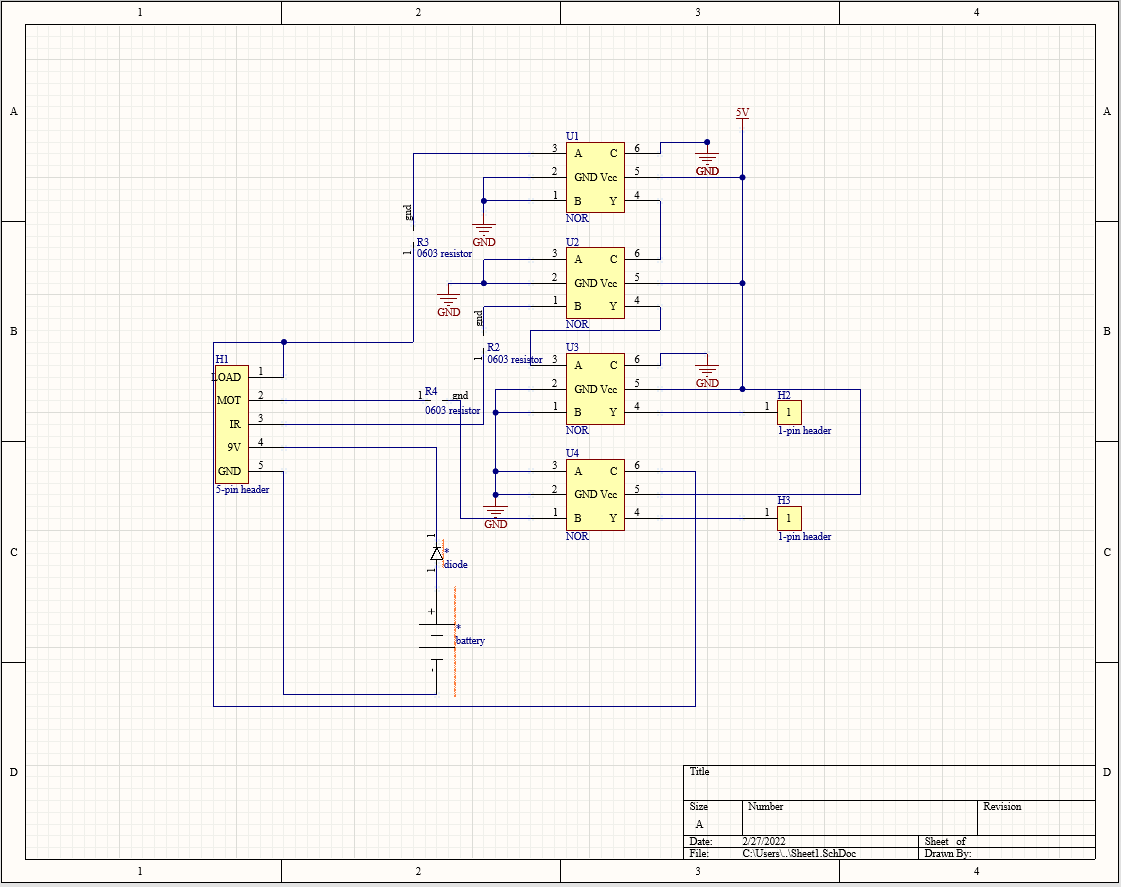
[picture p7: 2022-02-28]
DataSheet/PCB-Data/PCB-schematic.PNG

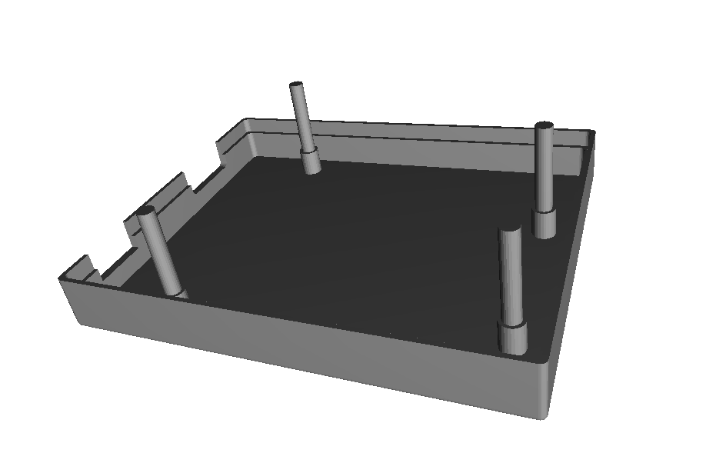
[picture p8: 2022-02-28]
DataSheet/3D-Model/bottom.png

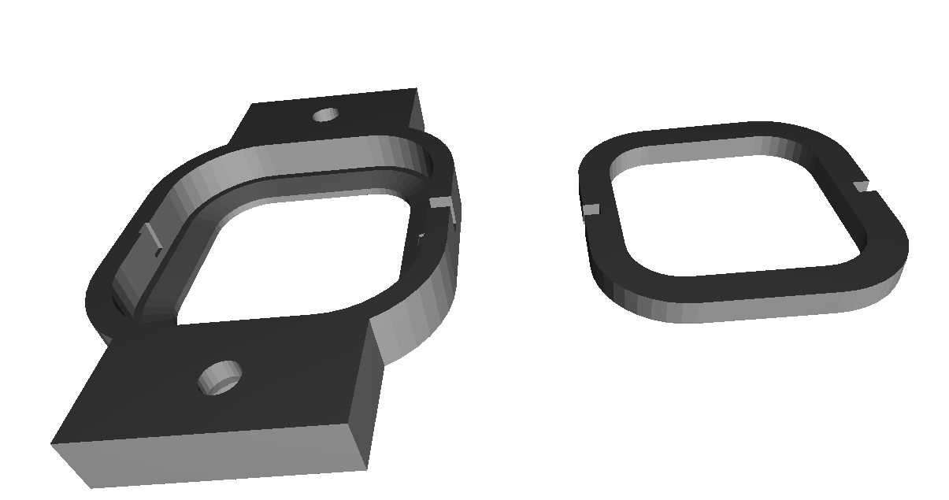
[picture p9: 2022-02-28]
DataSheet/3D-Model/loadcell.png

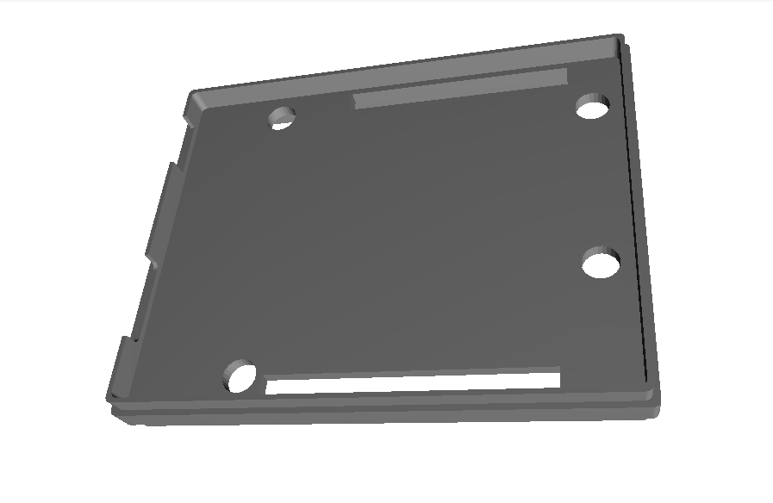
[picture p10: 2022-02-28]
DataSheet/3D-Model/middle.png

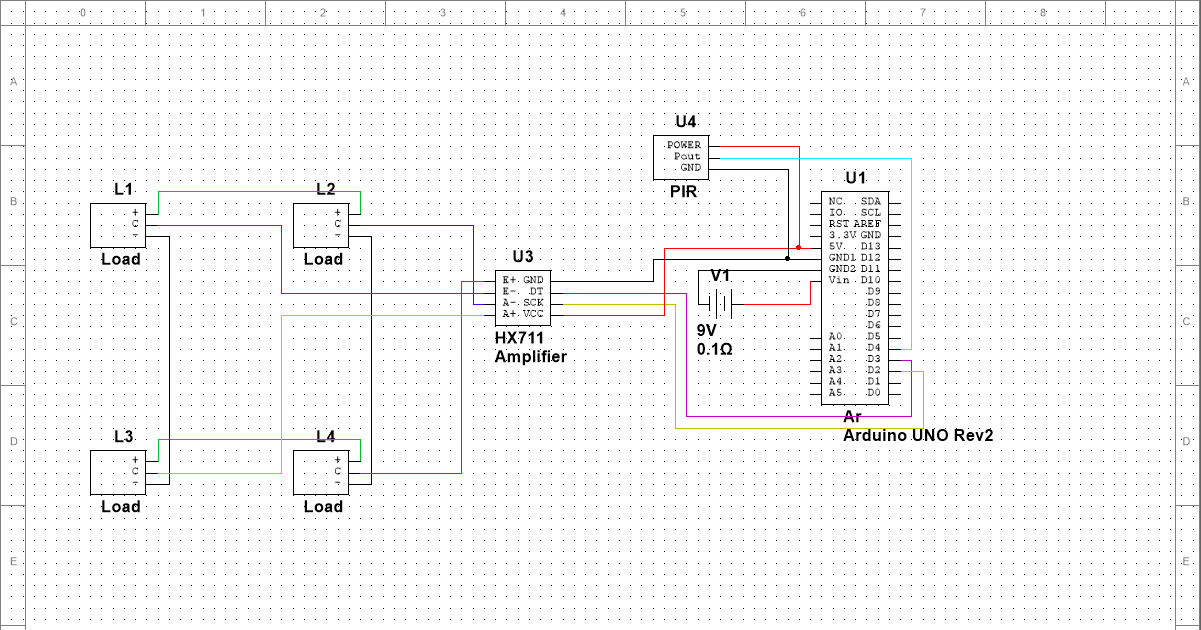
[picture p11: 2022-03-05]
DataSheet/Strain G.PNG

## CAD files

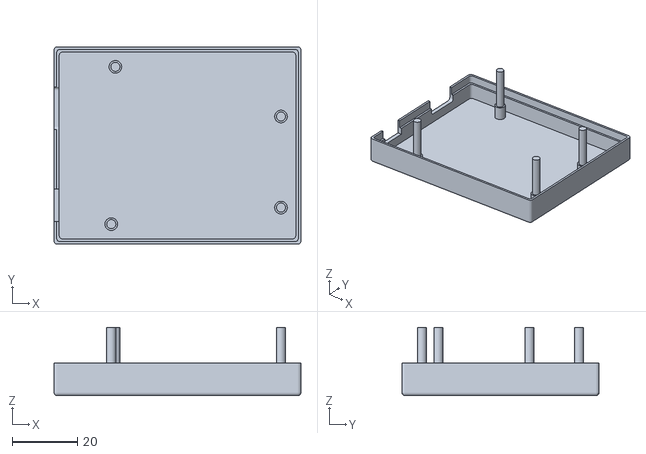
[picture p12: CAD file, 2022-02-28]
DataSheet/3D-Model/bottom.stl
75.8 x 60.5 x 21.0

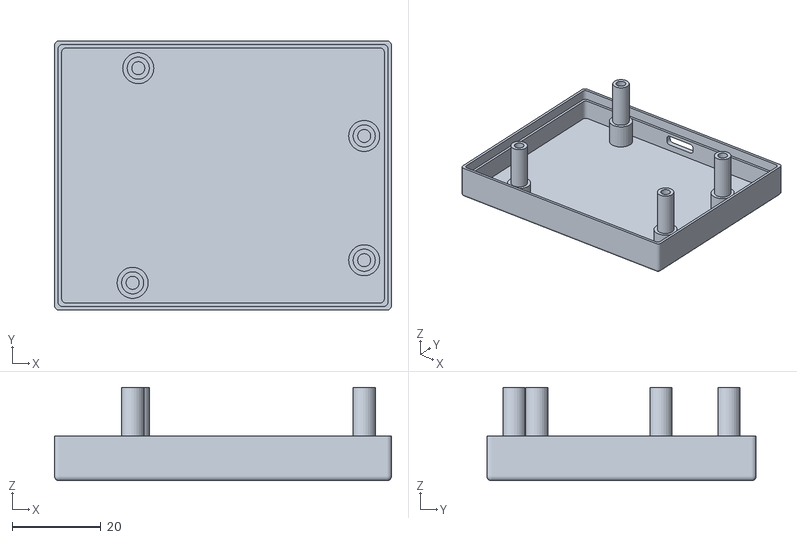
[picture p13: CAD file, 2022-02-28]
DataSheet/3D-Model/top.stl
75.8 x 60.5 x 21.0

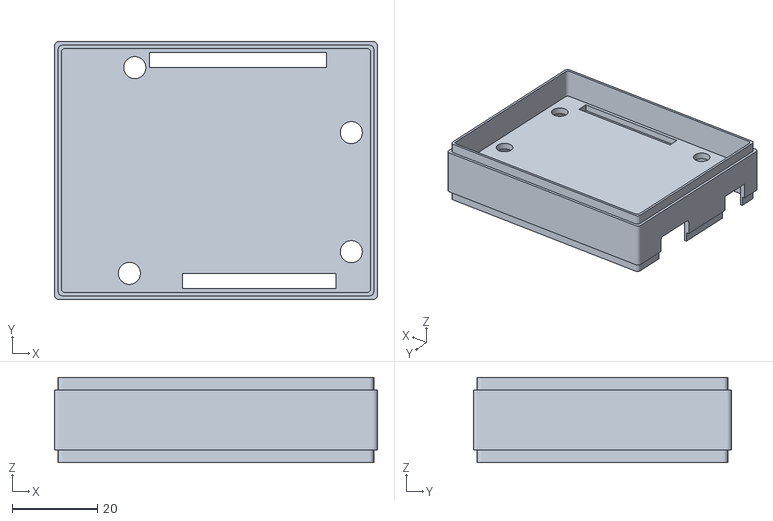
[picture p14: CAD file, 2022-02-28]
DataSheet/3D-Model/mid-Part.stl
75.8 x 60.5 x 20.0

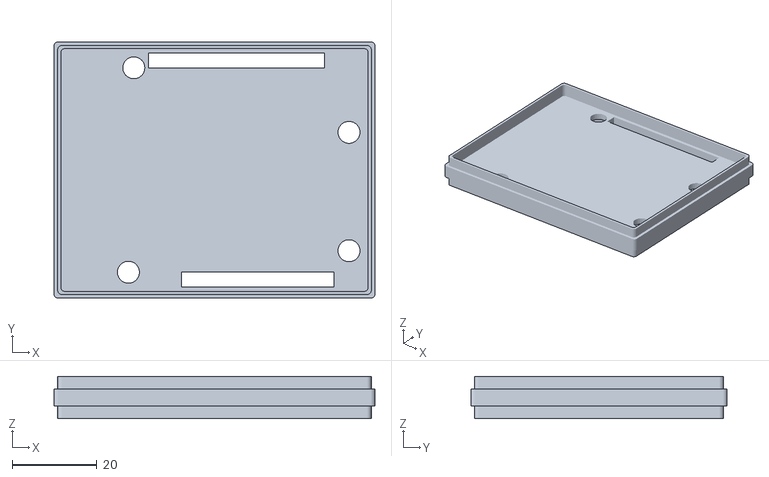
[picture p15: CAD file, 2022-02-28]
DataSheet/3D-Model/middle.stl
75.8 x 60.5 x 10.0

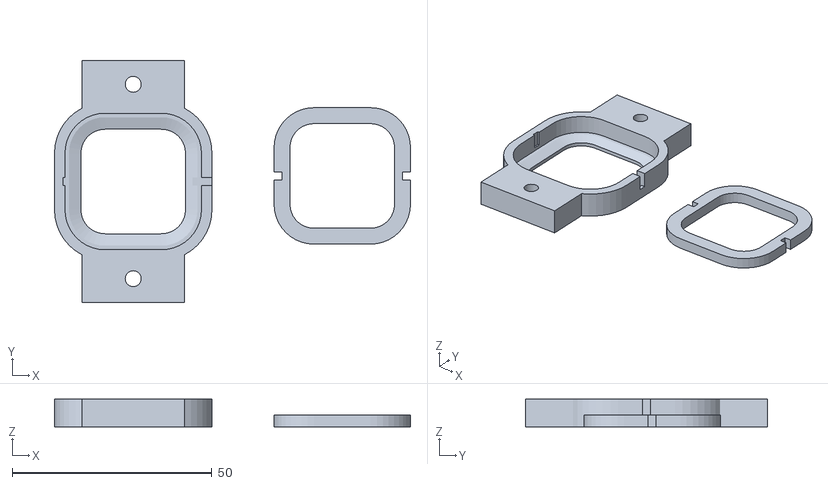
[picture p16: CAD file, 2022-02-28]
DataSheet/3D-Model/load cell.stl
89.2 x 60.7 x 7.00

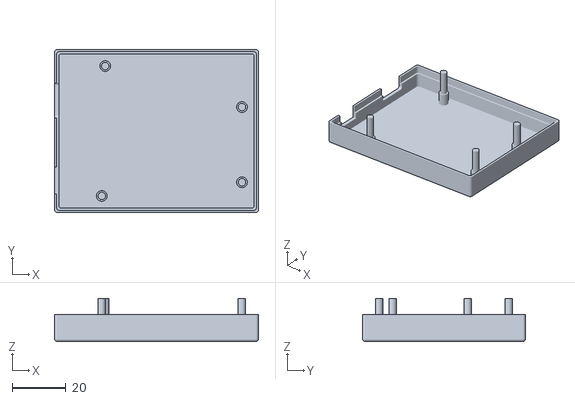
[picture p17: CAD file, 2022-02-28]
DataSheet/3D-Model/bot-Part.stl
75.8 x 60.5 x 16.0

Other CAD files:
DataSheet/3D-Model/50kgLoadcell-VersionF.stl

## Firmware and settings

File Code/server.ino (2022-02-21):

#include <SPI.h>
#include <WiFiNINA.h>

char ssid[] = "Jupiterbean";      // your network SSID (name)
char pass[] = "Ma351968";   // your network password
int keyIndex = 0;                 // your network key Index number (needed only for WEP)
int status = WL_IDLE_STATUS;

WiFiServer server(80);

void setup() {

  //Initialize serial and wait for port to open:
  Serial.begin(9600);

  while (!Serial) {
    ; // wait for serial port to connect. Needed for native USB port only
  }
  
  // check for the presence of the shield:
  if (WiFi.status() == WL_NO_SHIELD) {
    Serial.println("WiFi shield not present");

    // don't continue:
    while (true);
  }

  String fv = WiFi.firmwareVersion();

  if (fv != "1.1.0") {
    Serial.println("Please upgrade the firmware");
  }
  // attempt to connect to Wifi network:

  while (status != WL_CONNECTED) {
    Serial.print("Attempting to connect to SSID: ");
    Serial.println(ssid);

    // Connect to WPA/WPA2 network. Change this line if using open or WEP network:
    status = WiFi.begin(ssid, pass);

    // wait 10 seconds for connection:
    delay(10000);

  }

  server.begin();
  // you're connected now, so print out the status:
  printWifiStatus();
}

void loop() {
  // listen for incoming clients
  WiFiClient client = server.available();

  if (client) {
    Serial.println("new client");

    // an http request ends with a blank line
    bool currentLineIsBlank = true;

    while (client.connected()) {
      if (client.available()) {
        char c = client.read();
        Serial.write(c);

        // if you've gotten to the end of the line (received a newline
        // character) and the line is blank, the http request has ended,
        // so you can send a reply

        if (c == '\n' && currentLineIsBlank) {
          // send a standard http response header
          client.println("HTTP/1.1 200 OK");
          client.println("Content-Type: text/html");
          client.println("Connection: close");  // the connection will be closed after completion of the response
          client.println("Refresh: 5");  // refresh the page automatically every 5 sec
          client.println();
          client.println("<!DOCTYPE HTML>");
          
          // output HTML file
          client.println("<html>");
            client.println("<head>"); 
            client.println("<title> Changing Background Color in HTML</title>");
            client.println("</head>"); 
            client.println("<body bgcolor = #FFC0CB>");
            client.println("<h3>Changing Background Colors in HTML</h3>"); 
            client.println("<h4>Having fun changing colors in HTML </h4>"); 
            client.println("</body>"); 
            client.println("<br />");
          client.println("</html>");
          break;
        }

        if (c == '\n') {
          // you're starting a new line
          currentLineIsBlank = true;

        } else if (c != '\r') {
          // you've gotten a character on the current line
          currentLineIsBlank = false;
        }
      }
    }

    // give the web browser time to receive the data
    delay(1);

    // close the connection:
    client.stop();
    Serial.println("client disonnected");

  }
}

//function for outputing the status of the wifi connection
void printWifiStatus() {

  // print the SSID of the network you're attached to:
  Serial.print("SSID: ");
  Serial.println(WiFi.SSID());

  // print your WiFi shield's IP address:
  IPAddress ip = WiFi.localIP();
  Serial.print("IP Address: ");
  Serial.println(ip);

  // print the received signal strength:
  long rssi = WiFi.RSSI();

  Serial.print("signal strength (RSSI):");
  Serial.print(rssi);
  Serial.println(" dBm");
}

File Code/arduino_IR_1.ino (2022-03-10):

#define led 13




int s1,s2,range;
char dir;
unsigned long lastm;



void setup() {
Serial.begin(9600);
pinMode(led,OUTPUT);

digitalWrite(led,0);

range=100;
dir='x';

}//setup




void loop() {
s1=analogRead(A0);
s1=analogRead(A1);
delay(50);



if (s1>range){//sensor 1 detects object
  
if(dir=='x'){//if the last movement was unkown
dir='o';//movement is out going 
lastm=millis();  //give 2 seconds before ignoring the direction
}

if(dir=='i'){//sensor 2 is trigger first
Serial.println("direction is IN");
dir='x';
delay(1000);
}

}





if (s2>range){//sensor 2 detects object
  
if(dir=='x'){//if the last movement was unkown
dir='i';//movement is in going 
lastm=millis();  //give 2 seconds before ignoring the direction
}

if(dir=='o'){//sensor 1 is trigger first
Serial.println("direction is OUT");
dir='x';
delay(1000);
}

}


if(millis()-lastm>2000){//clear the direction flag every 2 seconds
dir='x';

lastm=millis();  
}

}//lop

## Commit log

2022-02-21 Rename Arduino WEBserver.txt to Code/Arduino WEBserver.txt
2022-03-07 Create Calibration for weights
2022-03-07 Create Calibration for weight
